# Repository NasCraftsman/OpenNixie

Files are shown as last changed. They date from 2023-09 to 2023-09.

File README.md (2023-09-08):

# OpenNixie 

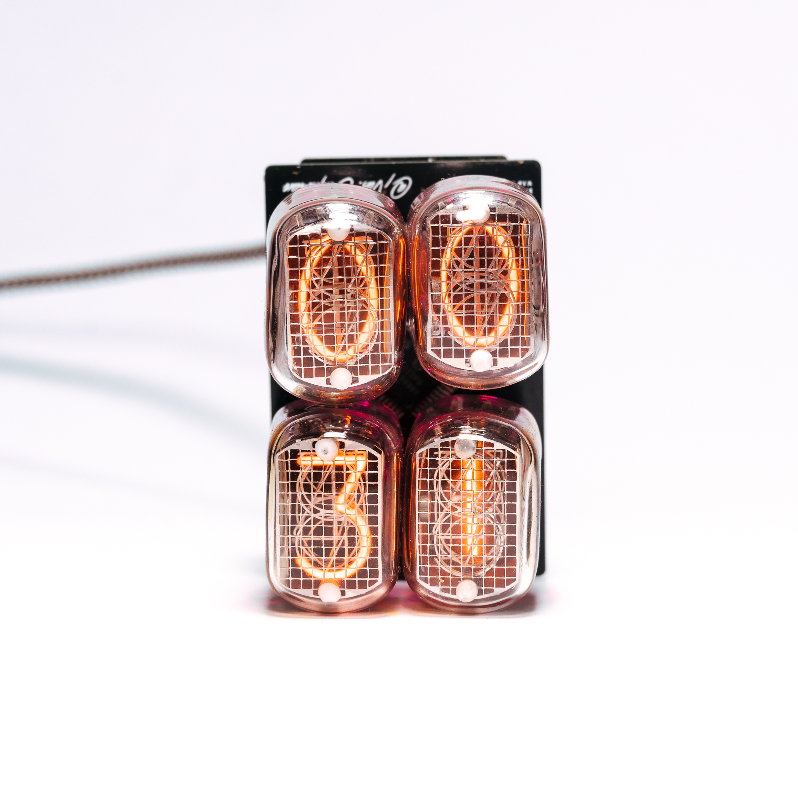
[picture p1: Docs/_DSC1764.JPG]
</a>
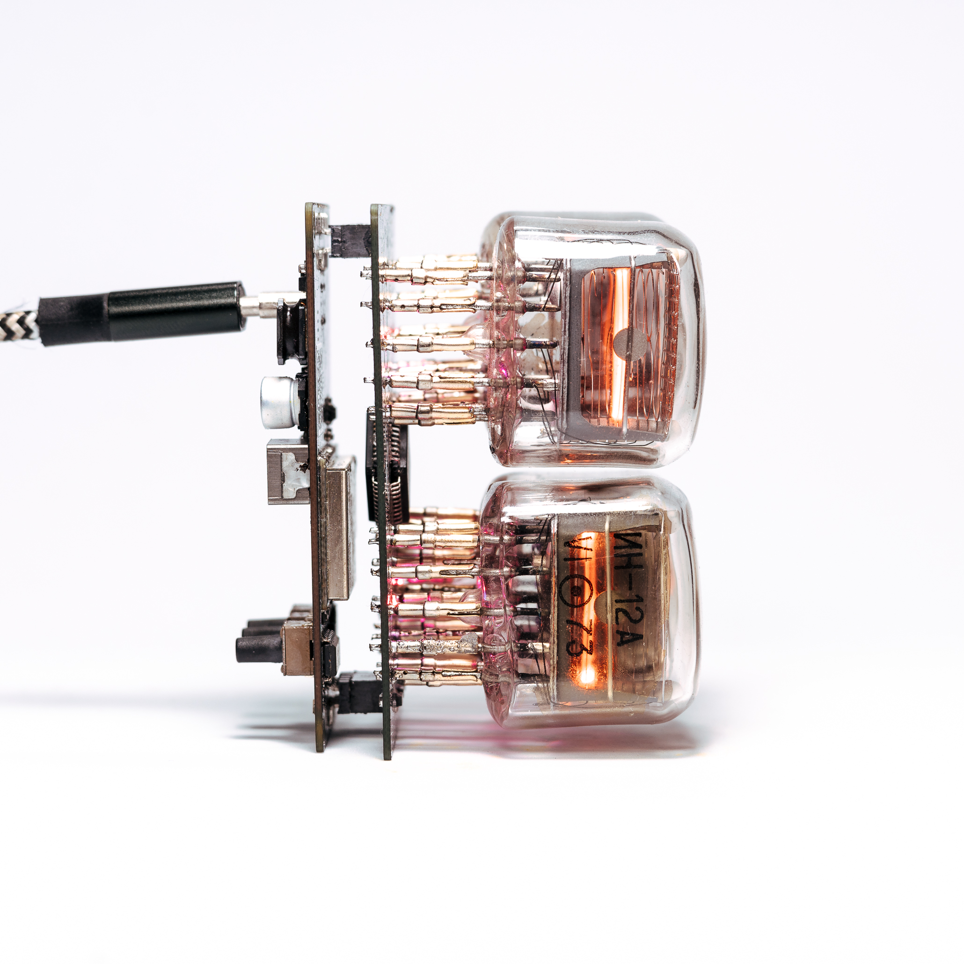
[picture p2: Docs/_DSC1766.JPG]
</a>
</a>

OpenNixie was born with the aim of creating an open project development platform around all types of Nixie Tubes. A platform that condenses the future with the past. The IoT technology with the famous plasma tubes in a miniature and modular design.

OpenNixie is a BLE and Wifi platform for different applications. It was originally designed as a RTC with an Internet connection, but later became a universal platform with many applications. This system is based on the ESP32-WROVER-IE Module, includes a 170V power stage and can be powered and programmed directly through the USB-C connector.

Some of the features that the OpenNixie platform includes are:

- Dimensions are only 30x60mm
- Wifi and BLE connected
- Modular design: it can be used for different Nixie tubes shapes and applications
- USB Type-C for power and programming
- 4 1N-12A + RGB lights as a default Nixie extension board 
- 1 general pourpose button for control the platform
- An internal accelerometer to interact with the display

<a href="https://www.pcbway.com/project/shareproject/Open_IoT_Nixie_Platform_9b133654.html" target="_blank">PCB from PCBWay</a>

## Multi Board Architecture
 
OpenNixie has been designed as a modular platform. This means that the control PCB can be connected to any PCB with Nixie tubes, so the applications are unlimited. At the moment the V2 version has been tested with a base for 4 1N-12A Nixies with RGB LEDs and SPI expansion.

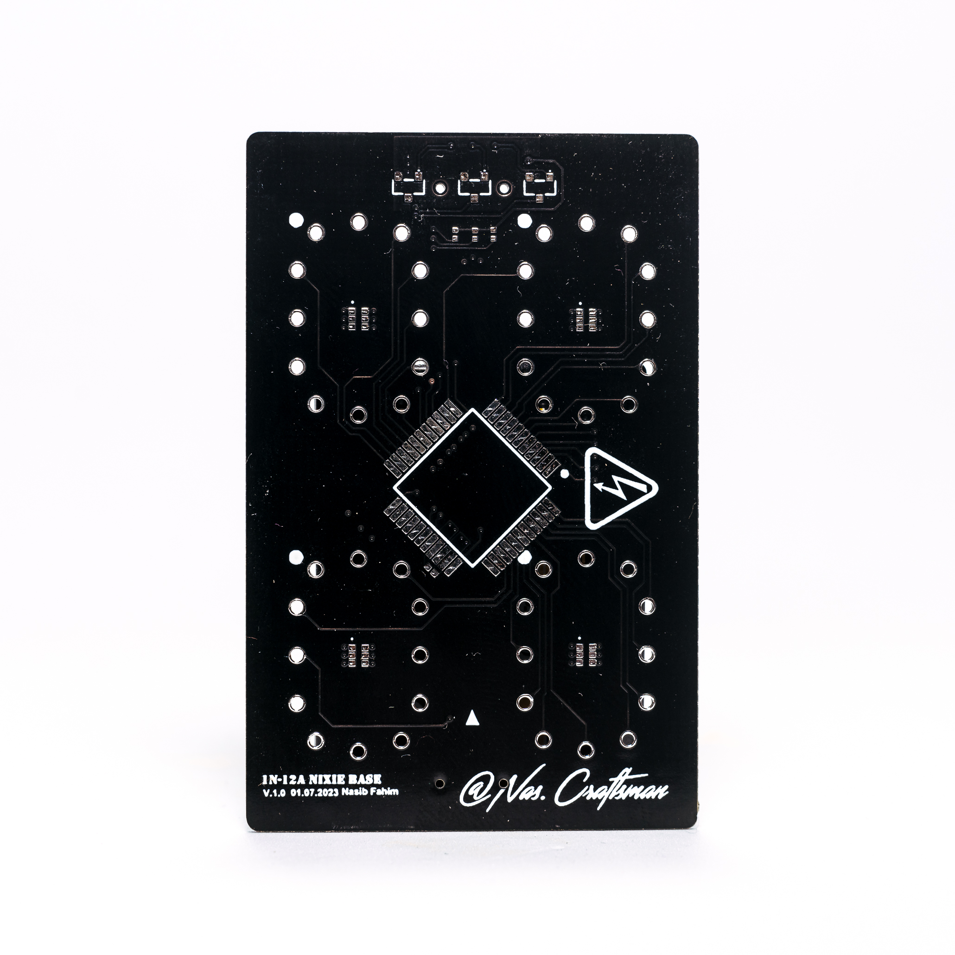
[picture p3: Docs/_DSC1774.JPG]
</a>
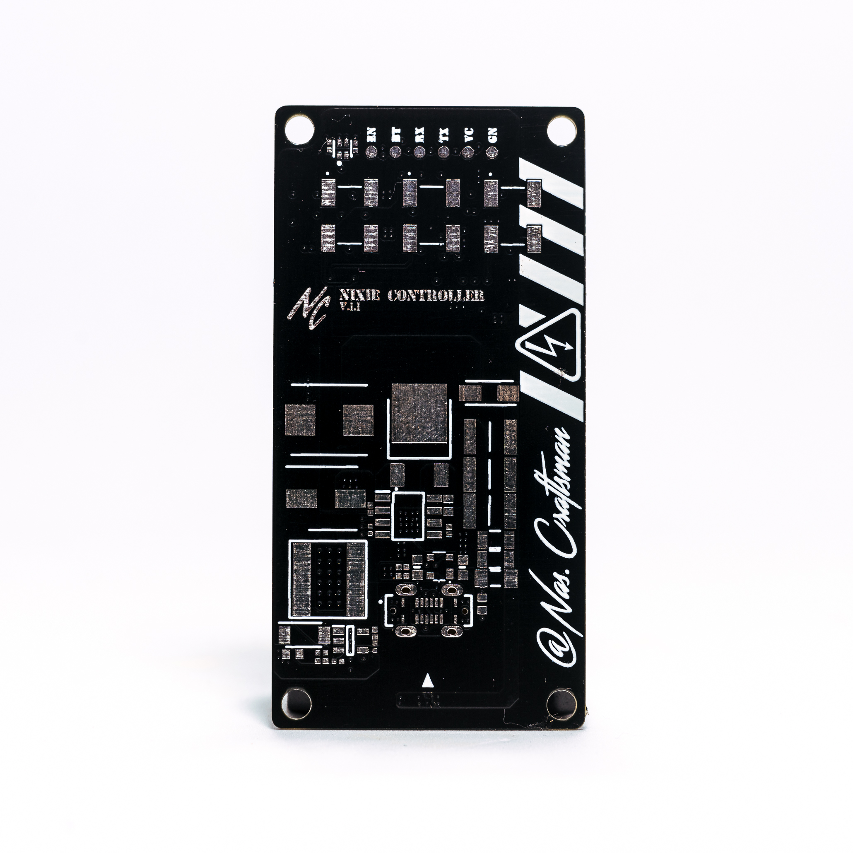
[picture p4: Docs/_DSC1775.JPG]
</a>

## Warning

OpenNixie uses the USB-C port to power the plasma tubes. For this, two power stages are created, one 12V LV and another 170V HV. The HV stage is limited to 1A, so it could be dangerous depending on the power supply used.

## GPIOs

Function | GPIO V2 | Mode
-------- | -------- | --------
SCK | GPIO2 | Output
MOSI | GPIO4 | Output
Button | GPIO15 | Input
I2C_SDA | GPI18 | Output/Input
I2C_SCL | GPI19 | Output
LED G | GPIO21 | Output
LED R | GPIO22 | Output
LED B | GPIO23 | Output
Logic EN | GPIO25 | Output
ACC INT | GPIO26 | Input
EN 170V | GPIO32 | Output
EN 12V | GPIO33 | Output

* The RGB signals control the background color of the ambient LEDs under the Nixie tubes
* The ACC INT signal is triggered by an event in the accelerometer
* The I2C bus controls the accelerometer
* To activate the Nixie tubes, the ignition sequence should be: EN12-ON EN170-OFF LE-ON
* To deactivate Nixie tubes, the shutdown sequence should be: LE-OFF EN170-ON EN12-OFF

## Control board overview 

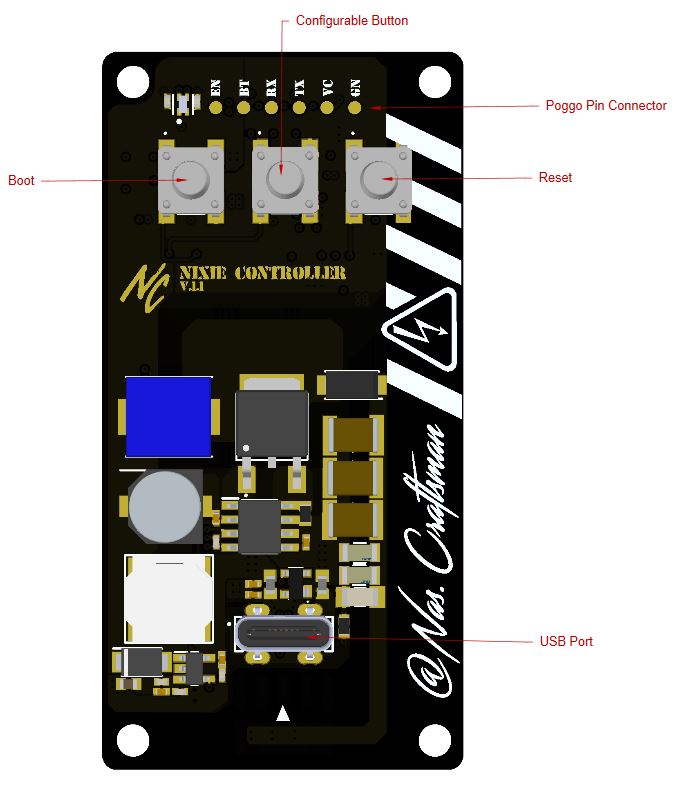
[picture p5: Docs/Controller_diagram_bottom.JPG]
</a>
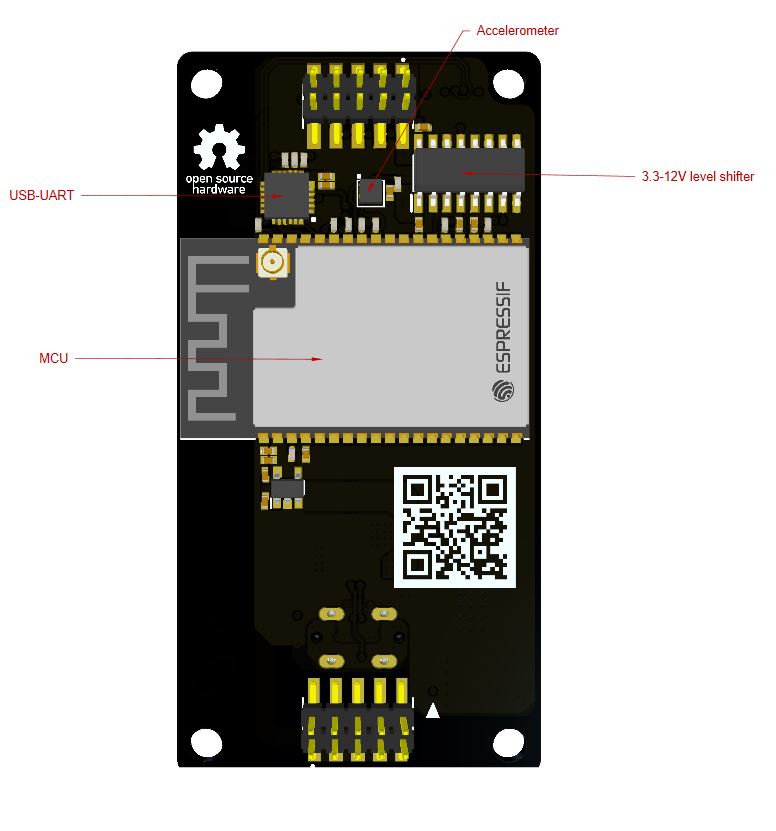
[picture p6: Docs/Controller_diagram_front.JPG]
</a>

## Flashing firmware 

- Press and hold BOOT button while press and release RESET button, then release BOOT button to enter in BOOT mode
- You can use the USB-C directly to programm the device

## Media

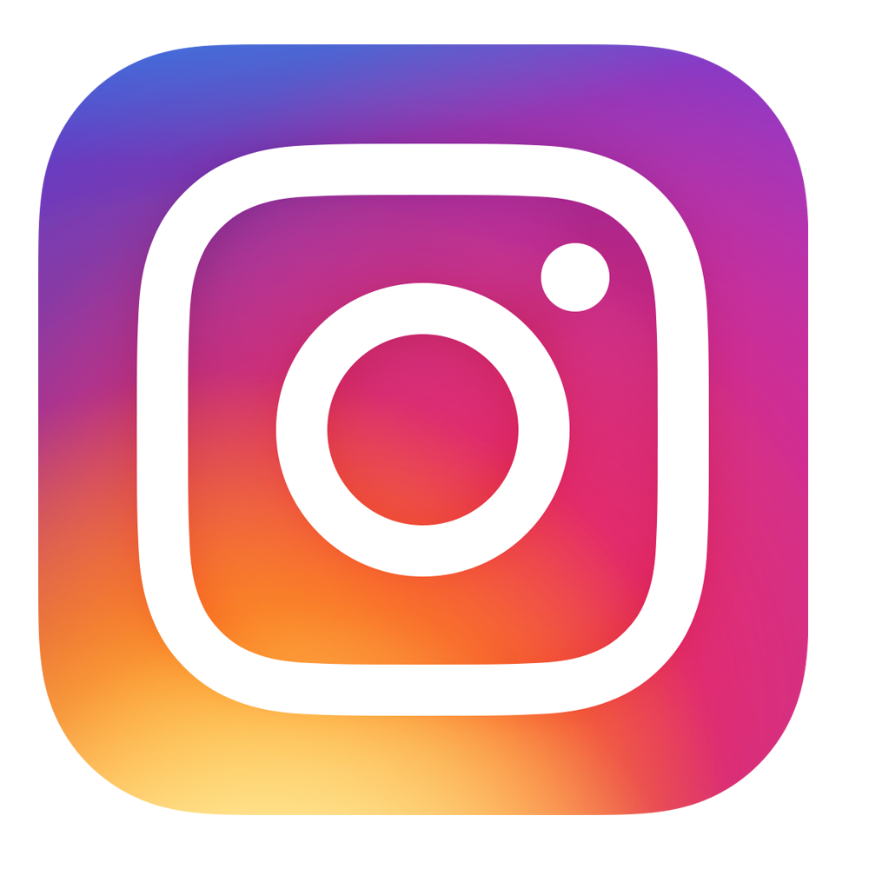
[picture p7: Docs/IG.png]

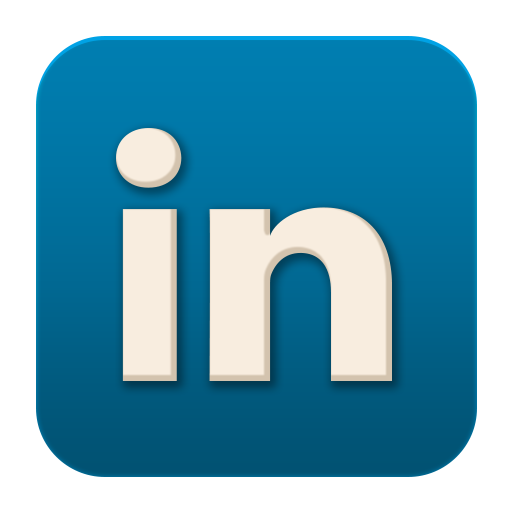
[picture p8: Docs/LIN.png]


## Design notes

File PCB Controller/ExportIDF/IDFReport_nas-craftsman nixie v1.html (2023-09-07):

Altium customize

# IDF File Translation Report

Date: | | 26/07/2023
Time: | | 13:23:11
Elapsed Time: | | 00:00:00
PCB Filename | : | F:\NASIB\INGENIERIA\PROYECTOS\Nixie project\V2\CONTROLLER\nas-craftsman nixie v1.PcbDoc
IDF Board Filename | : | F:\NASIB\INGENIERIA\PROYECTOS\Nixie project\V2\CONTROLLER\Project Outputs for nas-craftsman nixie v1\ExportIDF\nas-craftsman nixie v1.brd
IDF Library Filename | : | F:\NASIB\INGENIERIA\PROYECTOS\Nixie project\V2\CONTROLLER\Project Outputs for nas-craftsman nixie v1\ExportIDF\nas-craftsman nixie v1.pro

Errors

Back to top

Warnings

Back to top

Save Warnings

Back to top

Save Errors

Back to top

Export Warnings

Back to top

Export Errors

Back to top

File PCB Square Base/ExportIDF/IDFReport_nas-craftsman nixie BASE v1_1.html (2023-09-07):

Altium customize

# IDF File Translation Report

Date: | | 26/07/2023
Time: | | 13:10:11
Elapsed Time: | | 00:00:00
PCB Filename | : | F:\NASIB\INGENIERIA\PROYECTOS\Nixie project\V2\SQUARE BASE\nas-craftsman nixie BASE v1_1.PcbDoc
IDF Board Filename | : | F:\NASIB\INGENIERIA\PROYECTOS\Nixie project\V2\SQUARE BASE\Project Outputs for nas-craftsman nixie BASE v1\ExportIDF\nas-craftsman nixie BASE v1_1.brd
IDF Library Filename | : | F:\NASIB\INGENIERIA\PROYECTOS\Nixie project\V2\SQUARE BASE\Project Outputs for nas-craftsman nixie BASE v1\ExportIDF\nas-craftsman nixie BASE v1_1.pro

Errors

Back to top

Warnings

Back to top

Save Warnings

Back to top

Save Errors

Back to top

Export Warnings

Back to top

Export Errors

Back to top

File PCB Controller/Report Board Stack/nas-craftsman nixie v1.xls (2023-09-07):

Board Stack Report
Stack Up |  | Layer Stack
Layer | Board Layer Stack | Name | Material | Thickness | Constant
1 |  | Top Paste
2 |  | Top Overlay
3 |  | Top Solder | Solder Resist | 0,005mm | 4,2
4 |  | Top Layer | Copper | 0,035mm
5 |  | Dielectric 1 | PP-006 | 0,110mm | 4,1
6 |  | Mid1 | Copper | 0,035mm
7 |  | Core | FR-4 | 0,600mm | 4,29
8 |  | Mid2 | Copper | 0,035mm
9 |  | Dielectric 2 | PP-006 | 0,110mm | 4,1
10 |  | Bottom Layer | Copper | 0,035mm
11 |  | Bottom Solder | Solder Resist | 0,005mm | 4,2
12 |  | Bottom Overlay
13 |  | Bottom Paste
 | Height : 0,970mm

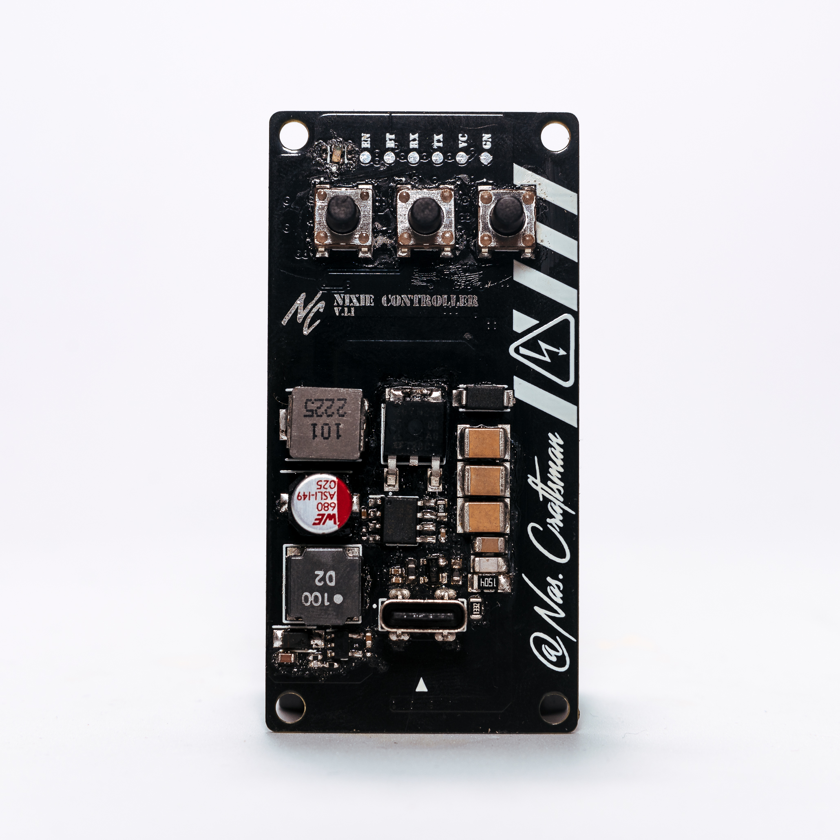
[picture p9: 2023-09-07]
Docs/_DSC1784.JPG

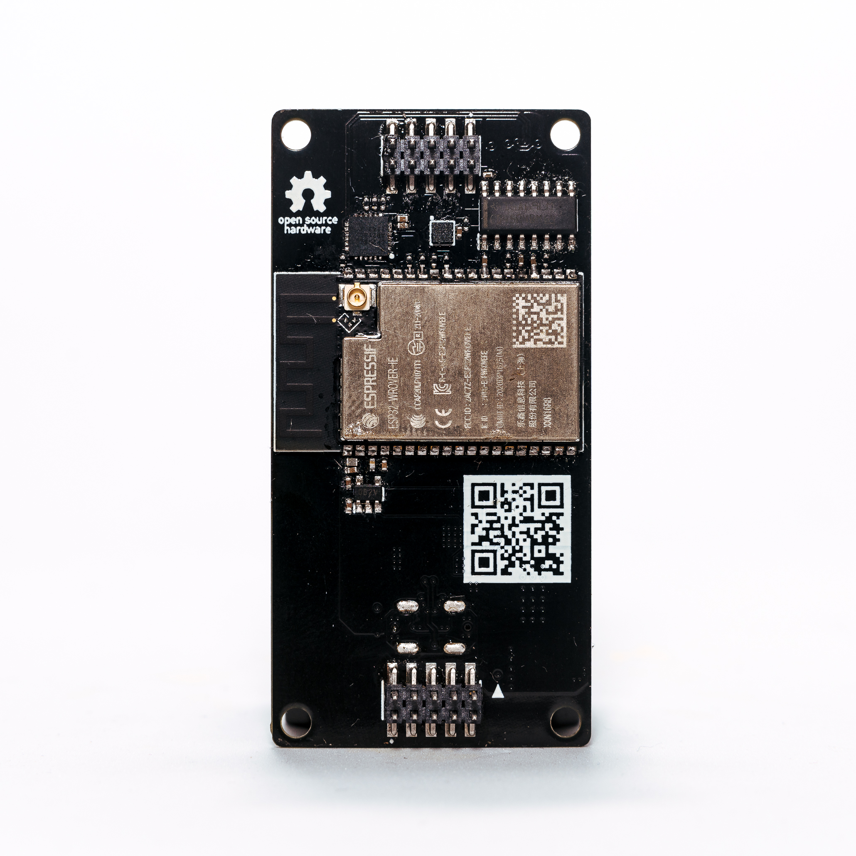
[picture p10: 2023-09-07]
Docs/_DSC1783.JPG

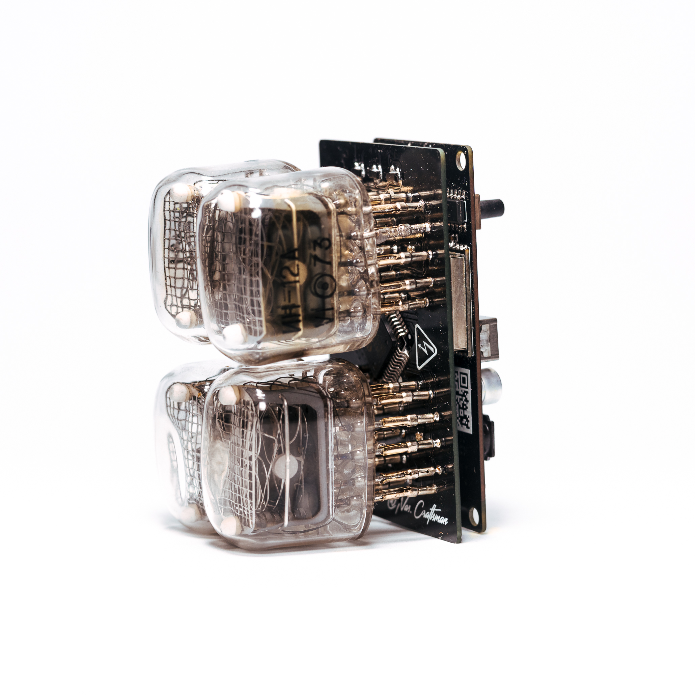
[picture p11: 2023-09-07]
Docs/_DSC1761.JPG

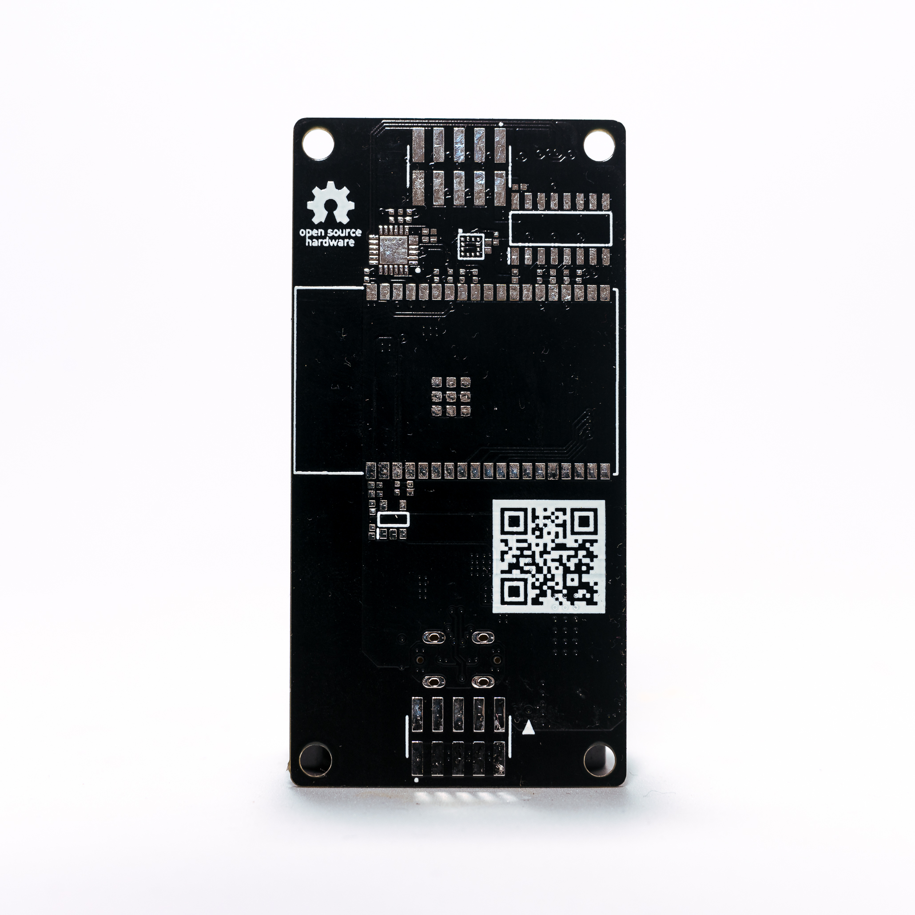
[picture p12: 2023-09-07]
Docs/_DSC1778.JPG

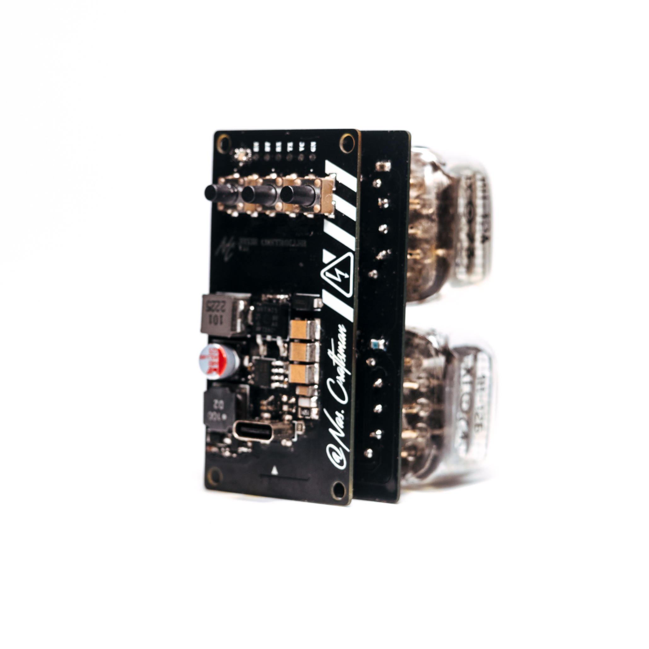
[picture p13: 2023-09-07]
Docs/_DSC1756.JPG

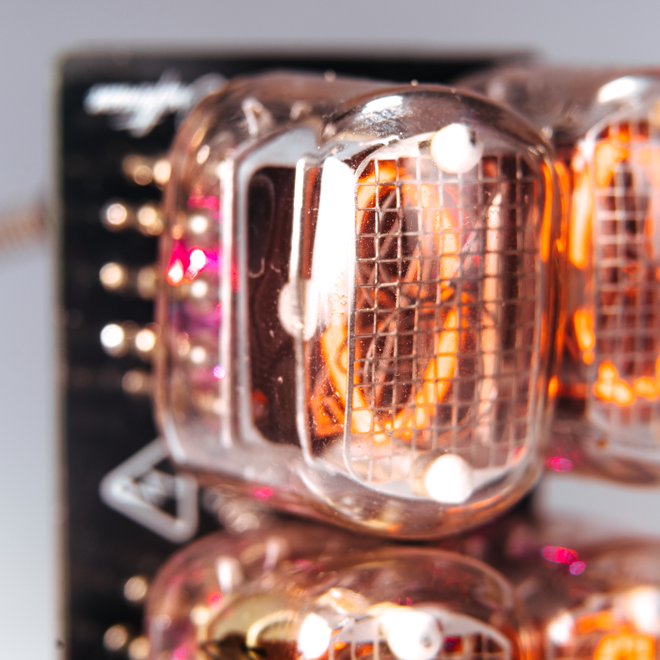
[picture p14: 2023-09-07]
Docs/_DSC1767.JPG

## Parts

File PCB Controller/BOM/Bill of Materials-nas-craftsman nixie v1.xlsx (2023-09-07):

Designator | Value | Description | Quantity | Part Number | Manufacturer | DNP
C100, C207, C208, C300, C302, C303, C304, C306, C307, C308, C309 | 100nF | CAP, MLCC, 0402/1005, 25V, X7R, | 11 | GRM155R71E104KE14D | Murata
C101 | 10nF | 0.01 uF 16 VDC 20% 0402 X7R | 1 | GRM155R71C103MA01D | Murata
C200, C201 | 1uF | 1.0uF 16V 10% 0402 X5R | 2 | GRM155R61C105KA12D | Murata
C203 | 10uF | 10 uF 25 VDC 10% 0603 X5R | 1 | GRM188R61E106KA73J | Murata Electronics
C204 | 270pF | 270 pF 25 VDC 5% 0402 C0G (NP0) | 1 | GRM1555C1E271JA01D | Murata
C205, C305 | 4.7uF | 4.7uF 10V 20% 0402 X5R | 2 | GRM155R61A475MEAAD | Murata
C206 | 68uF | SMD WCAP-ASLI 68uF 25V 20% SMD/SMT | 1 | 865080443009 | Wurth Elektronik
C209, C212, C213 | 1uF | 1812 MLCC X7R 1 uF, +/- 10% 200 V T&R GP | 3 | 1812B105K201CT | Walsin Technology Corporation
C210 | 100pF | 100 pF 500 VDC 5% 1206 C0G (NP0) | 1 | GRM31A5C2H101JW01D | Murata
C211 | 100nF | Cap Ceramic 100nF 250V X7R ±10% SMD 1206 +125°C Embossed T/R | 1 | CL31B104KEHSFNE | Samsung
C301 | 22uF | 22 uF 10 VDC 20% 0402 X5R | 1 | GRM158R61A226ME15D | Murata
D4 |  | LED GREEN/RED DIFFUSED 0603 SMD | 1 | HSMF-C165
D100 |  | Diode | 1 | PRTR5V0U2X | Nexperia
D200 |  | Super low VF Schottkey Barrier Diode for General rectification 2A 320mV | 1 | RBS2LAM40CTR | ROHM Semiconductor
D201 |  | Schottky 200V 3A | 1 | SS320-HF | Comchip Technology
FB100, FB101 |  | Ferrite Bead, 2A @ 100MHz, 120ohms 25% | 2 | ILHB0603ER121V | Vishay
J100 |  |  | 1 | USB4120-03-C | GCT
J101, J102 |  | Connector | 2 | TMM-105-01-T-D-SM-TR | SAMTEC
L200 |  | 8040 10uH 44.2mOhms +/-20% 3.1A | 1 | NR8040T100M | TAIYO YUDEN
L201 |  | 100uH+/-20%, 2.2A 357mOhms | 1 | SRP7050WA-101M | Bourns
Q200 |  | MOSFET N-Channel 250V AEC-Q101 Qualified | 1 | SQD07N25-350H_GE3 | Vishay
R200 | 118k | SMD 118 kOhms 62.5mW 0402 1% | 1 | RC0402FR-07118KL | Yageo
R201 | 13.3k | SMD 13.3 kOhms 62.5mW 0402 1% | 1 | RC0402FR-0713K3L | Yageo
R202, R203 | 100k | SMD 100kOhms 1/16W 0402 5% | 2 | RC0402JR-7D100KL | Yageo
R204 | 50m | SMD 0.05 ohm 0603 1% 0.20W | 1 | KDV06FR050ET | Ohmite
R205 | 1.5M | SMD 1.5 MOhms 250 mW 1206 1% | 1 | RC1206FR-071M5L | Yageo
R206 | 13.3k | SMD 13.3 kOhms 125 mW 0805 1% | 1 | RC0805FR-0713K3L | Yageo
R300, R307, R308 | 10k | SMD 10 kOhms 62.5mW 0402 1% | 3 | RC0402FR-0710KL | Yageo
R301 | 1M | SMD 1 MOhms 62.5mW 0402 5% | 1 | RC0402JR-071ML | Yageo
R302, R303 | 270 | RES SMD 270OHM 5% 1/16W 0402 | 2 | RC0402JR-07270RL | Yageo
R304 | 1k | SMD 1 kOhms 62.5mW 0402 5% | 1 | RC0402JR-071KL | Yageo
R305 | 22.1k | SMD 22.1kOhms 1/16W 0402 1% | 1 | RC0402FR-0722K1P | Yageo
R306 | 47.5k | SMD 47.5 kOhms 62.5mW 0402 1% | 1 | RC0402FR-0747K5L | Yageo
R309, R310 | 4k7 | SMD 4.7 kOhms 62.5mW 0402 5% | 2 | RC0402JR-074K7L | Yageo
R311, R312, R313 | 100 | SMD 100 Ohms 62.5mW 0402 1% | 3 | RC0402FR-07100RL | Yageo
S300, S302, S303 |  | Switch | 3 | TL3301BF160QJ | E-Switch
U200 |  | 700mA High Speed LDO Regulator | 1 | XC6210B332MR-G | Torex
U201 |  | 1.5A 1.6MHZ BOOST CONVERTER | 1 | LM2731XMF/NOPB | Texas Instruments
U202 |  | Integrated Circuit | 1 | MAX1771CSA+ | Analog Devices
U300 |  | RX TXRX MOD WIFI EXT IPEX SMD | 1 | ESP32-WROVER-IE(M213EH2864UH3Q0) | Espressif
U301 |  | Integrated Circuit | 1 | MC3479 | MEMSIC
U302 |  | USB to UART Bridge QFN24 | 1 | CP2102N-A02-GQFN24R | Silicon Labs
U303 |  | CMOS Quad Lo-to-Hi Vltg Level Shifter | 1 | CD4504BM96 | Texas Instruments

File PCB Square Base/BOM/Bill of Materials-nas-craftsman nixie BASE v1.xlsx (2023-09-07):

Designator | Value | Description | Quantity | Part Number | Manufacturer | DNP
C100, C101 | 100nF | CAP, MLCC, 0402/1005, 25V, X7R, | 2 | GRM155R71E104KE14D | Murata
J100, J101 |  | Connector | 2 | TLE-105-01-G-DV-A | SAMTEC
LED100, LED101, LED102, LED103 |  | LED | 4 | IN-S66TFT5R5G5B | Inolux
N100, N101, N102, N103 |  | Undefined or Miscellaneous | 4 | 1N- 12A | Reflector/Sovtec | DNP
Q100, Q101, Q102 |  | MOSFET (N-Channel) | 3 | T2N7002AK,LM | Toshiba
R100, R101, R102, R103 | 15.8k | SMD 1/4W 15.8K OHM 1% | 4 | RK73H2ATTD1582F | KOA Speer
R104 | 200 | SMD 200 Ohms 62.5 mW 0402 1% | 1 | RE0402FRE07200RL | Yageo
R105, R106 | 150 | SMD 150 Ohms 62.5mW 0402 1% | 2 | RC0402FR-07150RL | Yageo
U100, U101 |  | HV OD Outs Serial to Parallel Converter | 2 | HV5222PG-G | Microchip

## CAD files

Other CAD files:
PCB Square Base/ExportSTEP/nas-craftsman nixie BASE v1_1.x_t

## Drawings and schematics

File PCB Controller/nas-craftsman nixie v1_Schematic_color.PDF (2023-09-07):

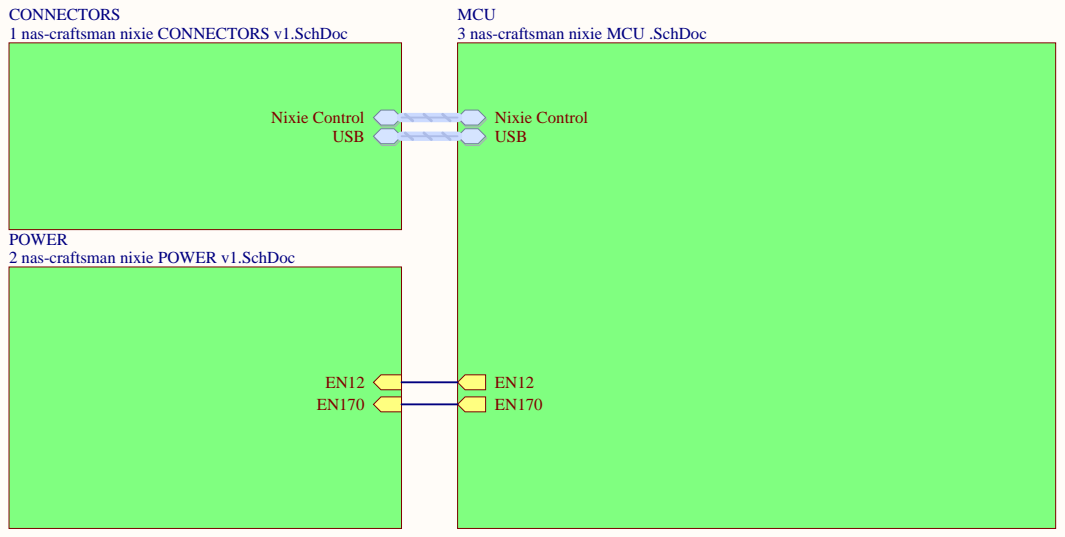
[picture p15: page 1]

CONNECTORS
1 nas-craftsman nixie CONNECTORS v1.SchDoc

MCU
3 nas-craftsman nixie MCU .SchDoc

POWER
2 nas-craftsman nixie POWER v1.SchDoc

Title MAIN

Number 0 | Project nas-craftsman nixie v1.PrjPcb | Revision v1

Created by: Nasib Fahim Fernández | | Date 26/07/2023

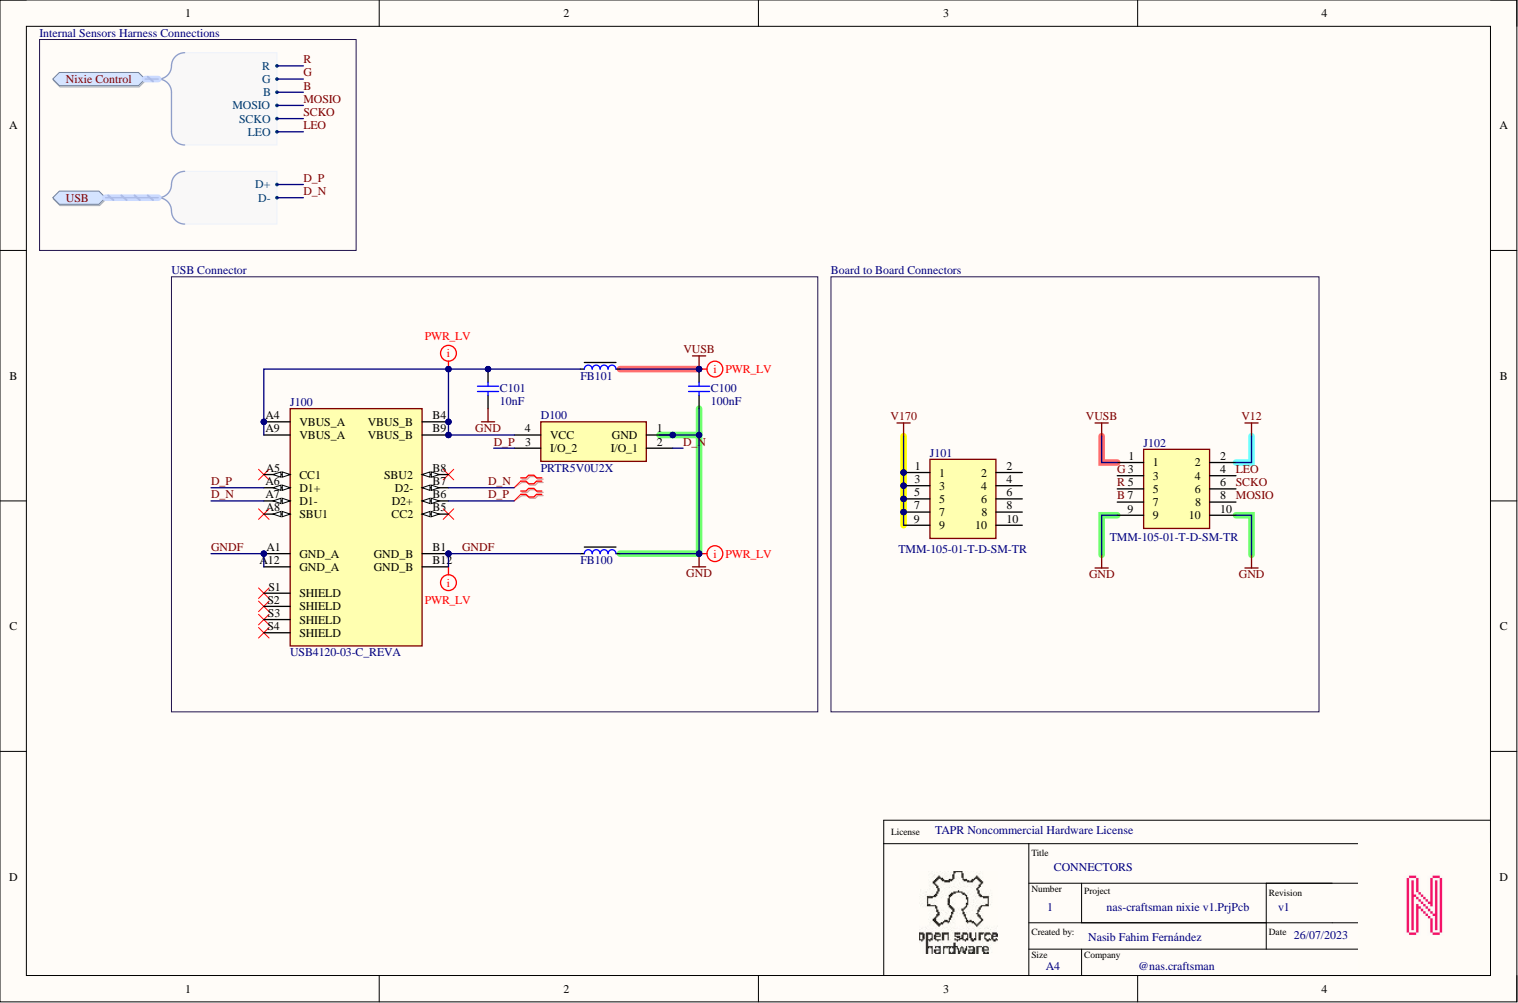
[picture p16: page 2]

Internal Sensors Harness Connections

Title CONNECTORS

Number 1 | Project nas-craftsman nixie v1.PrjPcb | Revision v1

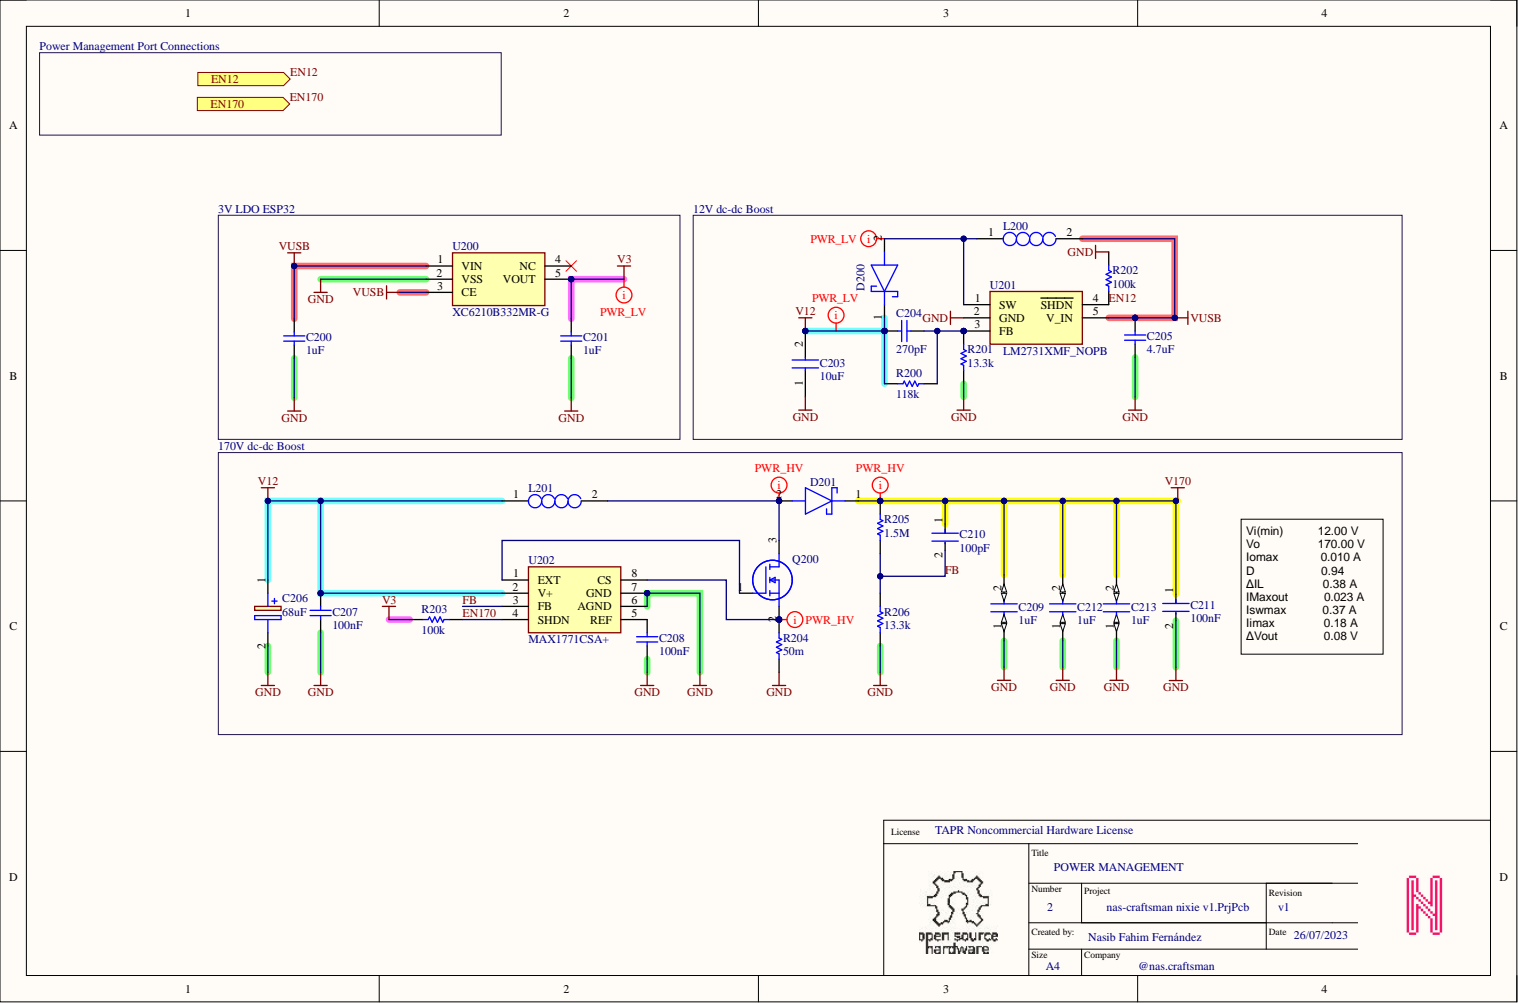
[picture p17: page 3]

Power Management Port Connections

Title POWER MANAGEMENT

Number 2 | Project nas-craftsman nixie v1.PrjPcb | Revision v1

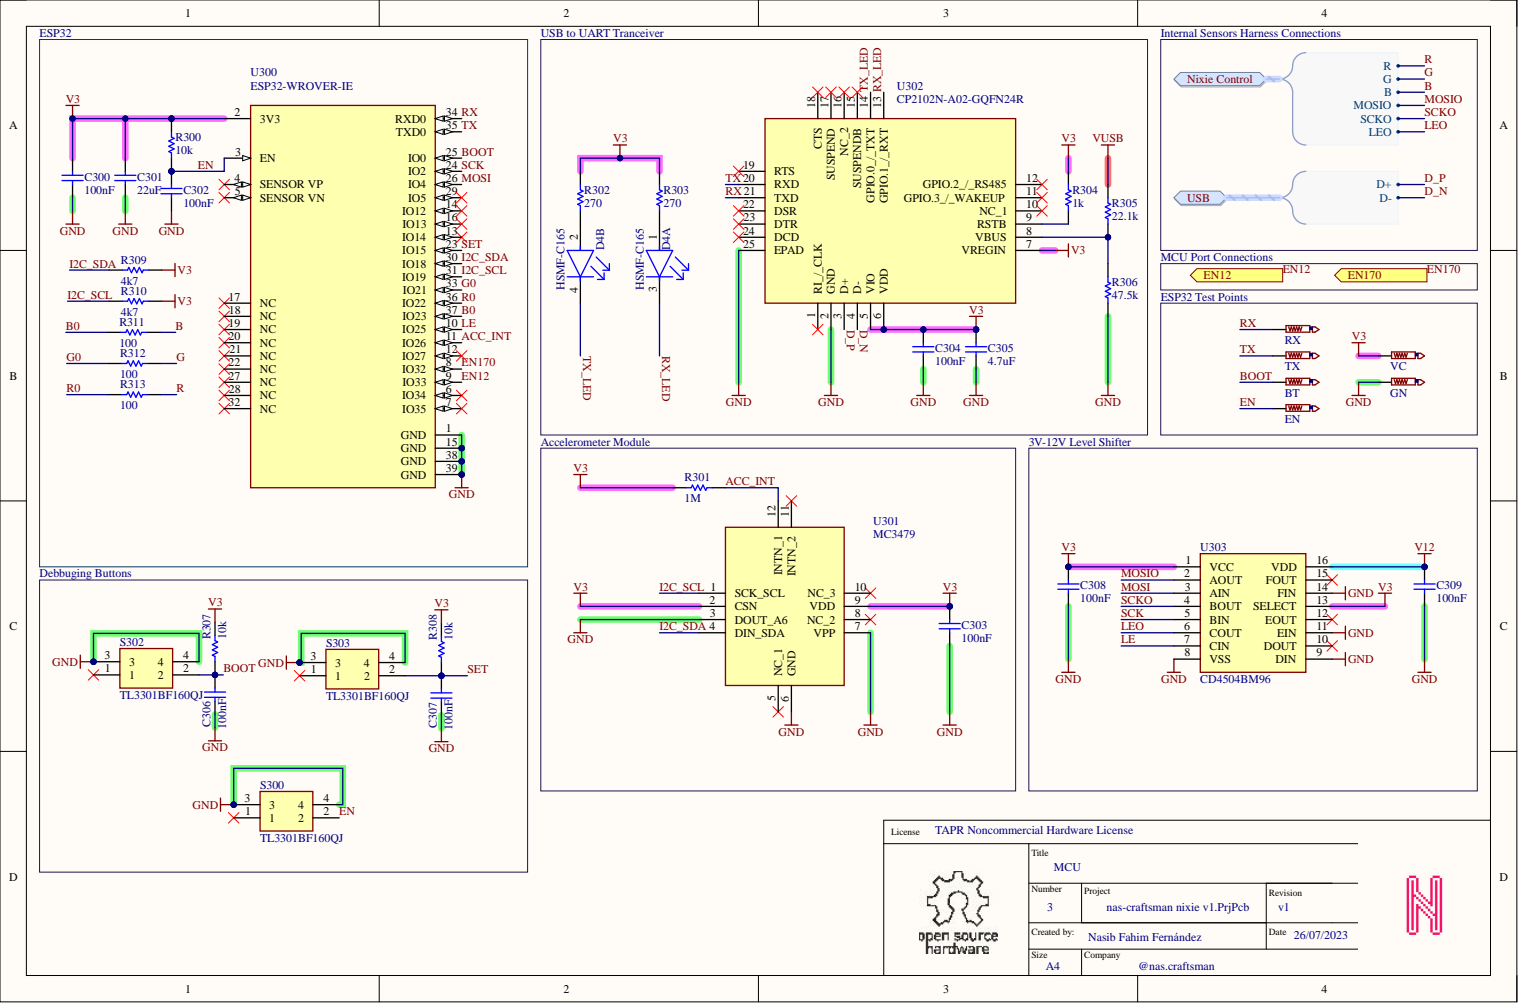
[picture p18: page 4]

USB to UART Tranceiver

Internal Sensors Harness Connections

EN | | SENSOR VN 5 SENSOR VP 4

Title MCU

Number 3 | Project nas-craftsman nixie v1.PrjPcb | Revision v1

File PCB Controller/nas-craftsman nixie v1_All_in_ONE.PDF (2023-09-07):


CONNECTORS
1 nas-craftsman nixie CONNECTORS v1.SchDoc

MCU
3 nas-craftsman nixie MCU .SchDoc

POWER
2 nas-craftsman nixie POWER v1.SchDoc

Title MAIN

Number 0 | Project nas-craftsman nixie v1.PrjPcb | Revision v1

Created by: Nasib Fahim Fernández | | Date 26/07/2023


Internal Sensors Harness Connections

Title CONNECTORS

Number 1 | Project nas-craftsman nixie v1.PrjPcb | Revision v1

Created by: Nasib Fahim Fernández | | Date 26/07/2023


Power Management Port Connections

Title POWER MANAGEMENT

Number 2 | Project nas-craftsman nixie v1.PrjPcb | Revision v1

Created by: Nasib Fahim Fernández | | Date 26/07/2023


USB to UART Tranceiver

Internal Sensors Harness Connections

EN | | SENSOR VN 5 SENSOR VP 4

Title MCU

Number 3 | Project nas-craftsman nixie v1.PrjPcb | Revision v1

Created by: Nasib Fahim Fernández | | Date 26/07/2023

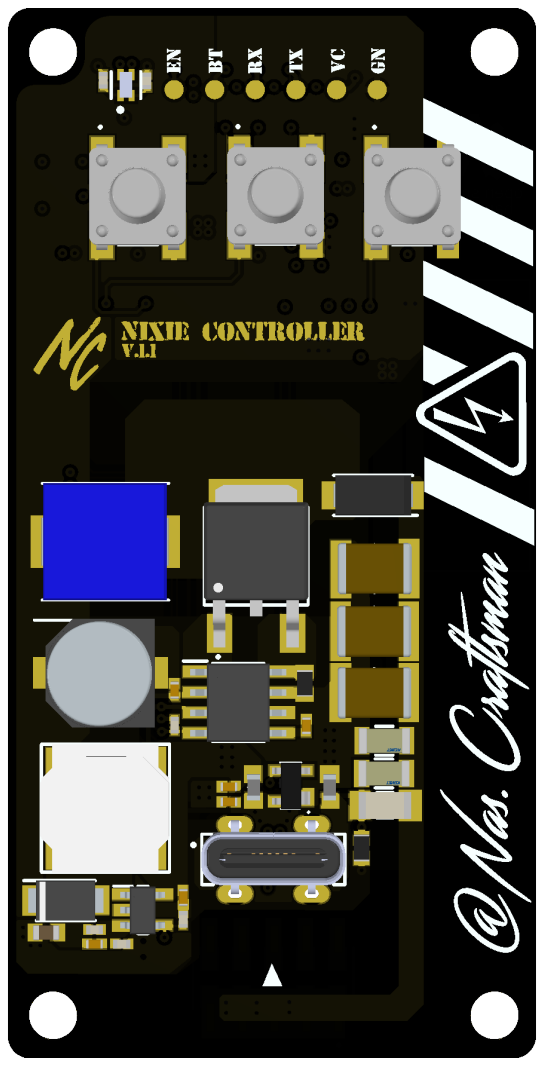
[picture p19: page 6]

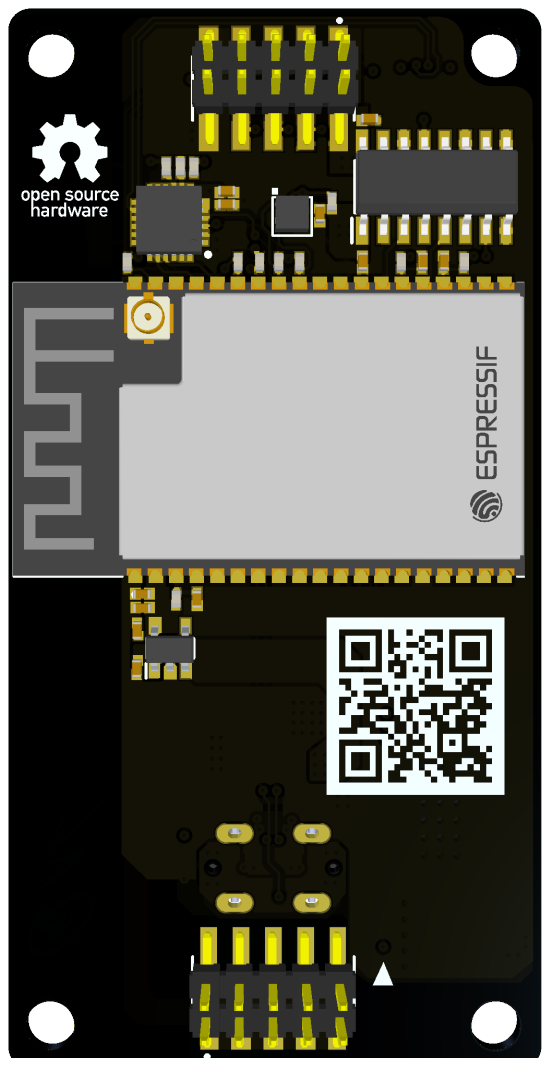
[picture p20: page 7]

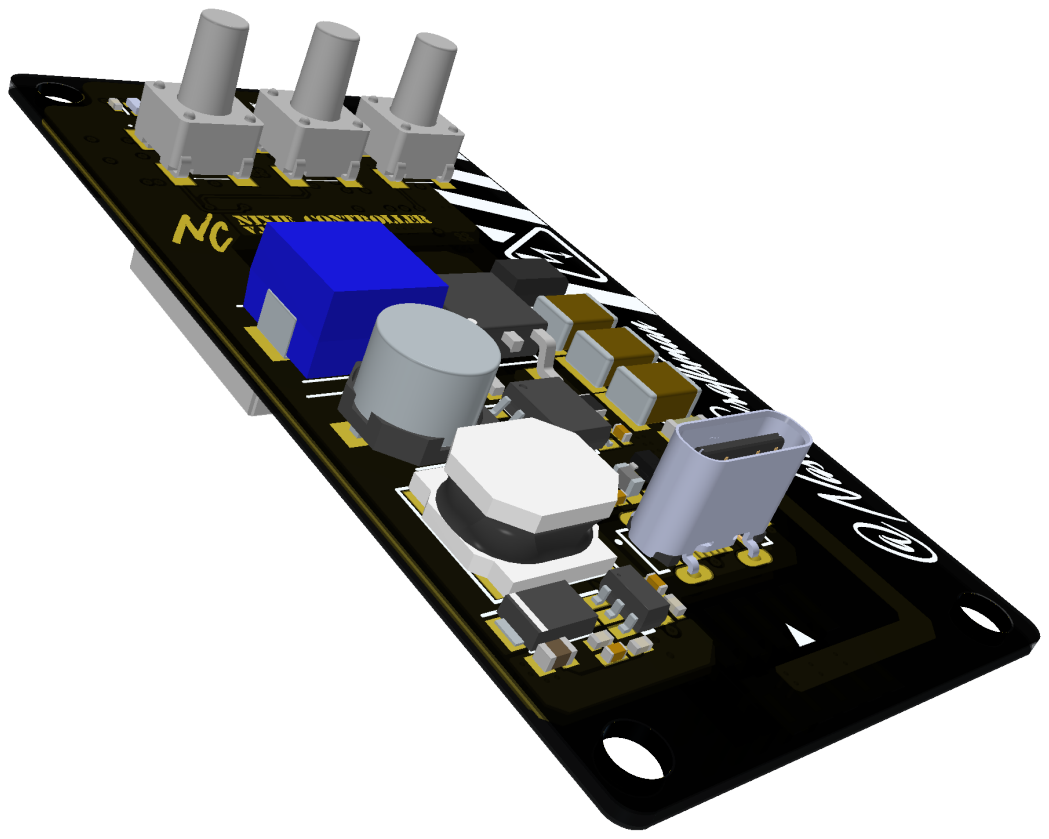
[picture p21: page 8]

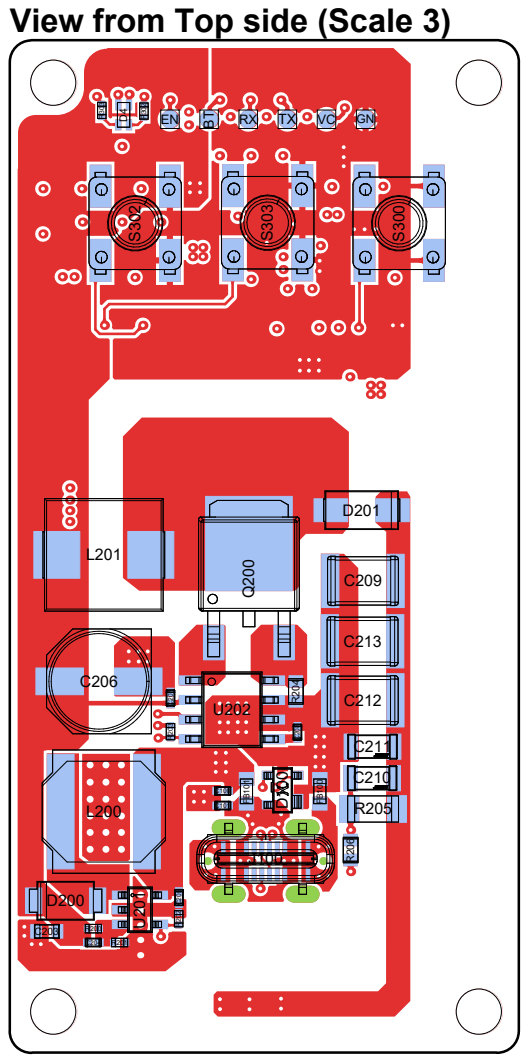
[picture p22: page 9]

View from Top side (Scale 3)

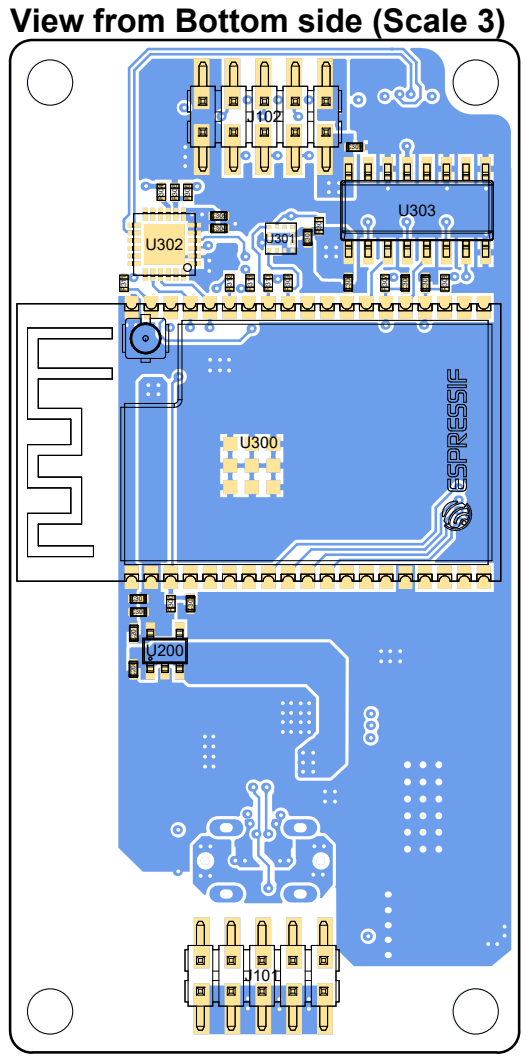
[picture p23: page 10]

View from Bottom side (Scale 3)

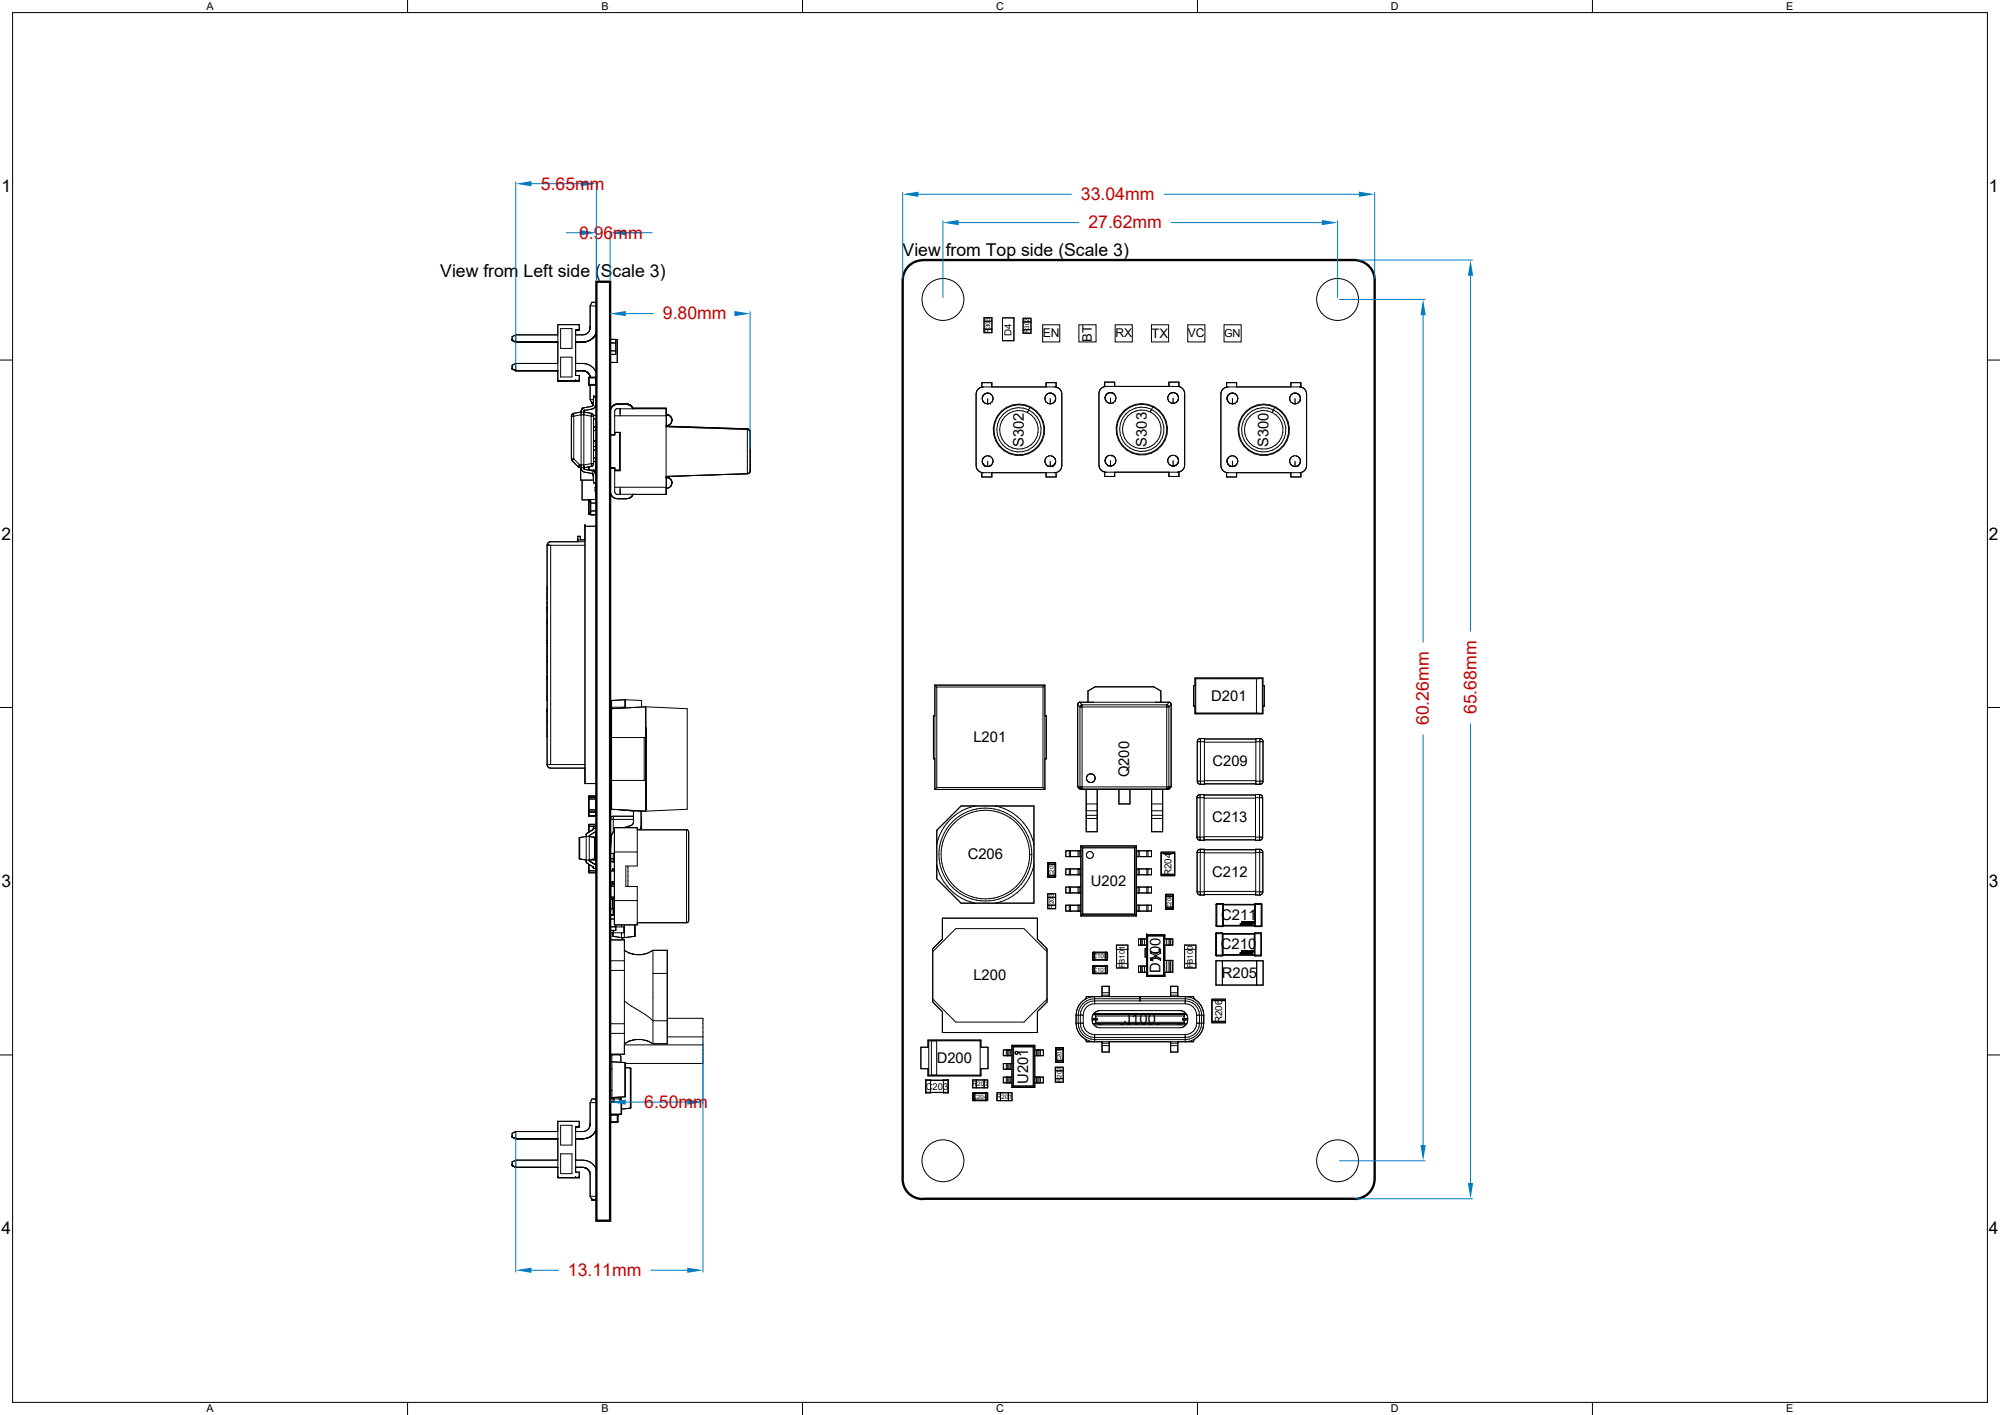
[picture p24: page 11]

View from Top side (Scale 3)

View from Left side (Scale 3)

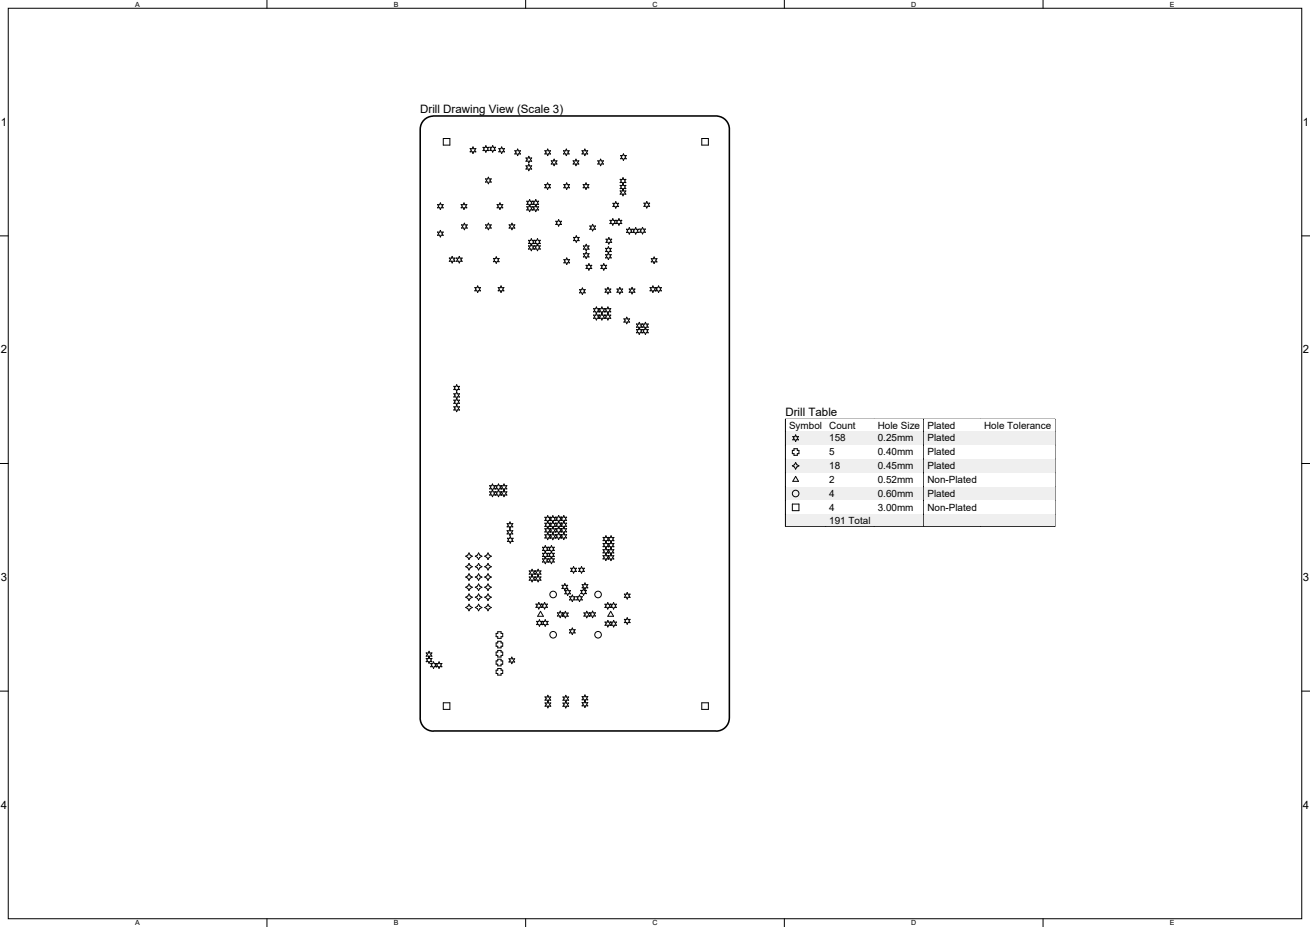
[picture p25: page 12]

Drill Drawing View (Scale 3)

Symbol | Count | Hole Size | Plated | Hole Tolerance

158 | 0.25mm | Plated
5 | 0.40mm | Plated
18 | 0.45mm | Plated
2 | 0.52mm | Non-Plated
4 | 0.60mm | Plated
4 | 3.00mm | Non-Plated
191 Total

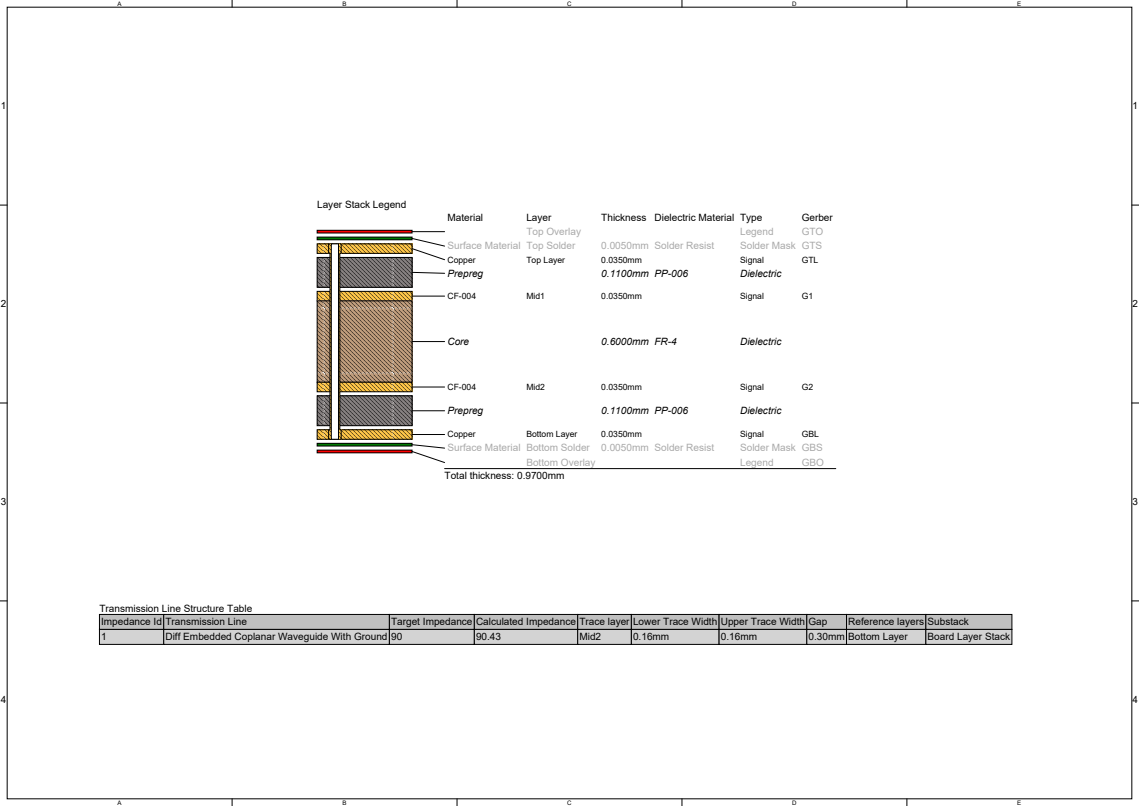
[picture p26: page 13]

Transmission Line Structure Table

Impedance Id | Transmission Line | Target Impedance | Calculated Impedance | Trace layer | Lower Trace Width | Upper Trace Width | Gap | Reference layers | Substack
1 | Diff Embedded Coplanar Waveguide With Ground | 90 | 90.43 | Mid2 | 0.16mm | 0.16mm | 0.30mm | Bottom Layer | Board Layer Stack





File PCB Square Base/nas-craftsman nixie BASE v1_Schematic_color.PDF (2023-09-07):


Title MAIN

Number 0 | Project nas-craftsman nixie BASE v1.PrjPcbv1 | Revision

Created by: Nasib Fahim Fernández | | Date 26/07/2023

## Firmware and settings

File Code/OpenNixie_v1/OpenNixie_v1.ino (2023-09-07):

//////////////////////////////////////////////////////////////////////////////////////////////////////////////////////
//
//  OPEN NIXIE FANTASY PROJECT
//
//  Modes: (press fast two times the center button to change the mode)
//  * Mode0-dice
//  * Mode1-cronometer 
//  * Mode2-universal clock 
//  * Mode3-work break counter
//
//  The circuit:
//  * This code is made to be used with the NixeFantasy Controller V2 and the NixieFantasy Square Base V2
//
//  The License: 
//  * Created in 2023 by nas.craftsman https://github.com/NasCraftsman
//  * This example code is in the public domain.
//
//////////////////////////////////////////////////////////////////////////////////////////////////////////////////////
//                       NixieFantasy Square Base V1
//
//    Nixie 1:N100
//    o o
//    o x
//    clk 1-10
//  
//    Nixie 2:N101
//    o o
//    x o
//    clk 11-20
//  
//    Nixie 3:N101
//    x o
//    o o
//    clk 21-30
//    Nixie 4:N100
//    o x
//    o o
//    clk 31-40
//
//////////////////////////////////////////////////////////////////////////////////////////////////////////////////////


#include <WiFi.h>
#include <AsyncTCP.h>
#include <ESPAsyncWebServer.h>
#include <HTTPClient.h>
#include "time.h"

const char* ssid     = "prue";
const char* password = "ojetecalor";
const char* ntpServer = "pool.ntp.org";
const long  gmtOffset_sec = 0;
const int   daylightOffset_sec = 3600;

#define SET       15      // General purpose button
#define SCK       2       // SPI sck pin
#define MOSI      4       // SPI MOSI pin
#define MISO      27       // SPI MISO pin
#define SS        34       // SPI MISO pin
#define SDA       18      // I2C SDA pin
#define SCL       19      // I2C SCL pin
#define R         22      // R LEDs pin
#define G         21      // G LEDs pin
#define B         23      // B LEDs pin
#define LE        25      // Nixies serial-parallel enable pin
#define ACC_INT   26      // Accelerometer interrupt pin 
#define EN_170    32      // 170V Enable pin 
#define EN_12     33      // 12V Enable pin 

#define LEDC_TIMER_13_BIT  13   // Use 13 bit precission for LEDC timer
#define LEDC_BASE_FREQ     5000 // Use 5000 Hz as a LEDC base frequency 
#define LEDC_CHANNEL_0     0    // Use first channel of 16 channels (started from zero)
#define LEDC_CHANNEL_1     1
#define LEDC_CHANNEL_2     2

//-----------------------AP PARAMETERS------------------------------------//
/* Put your SSID & Password */
const char* ssid_ap = "NIXIES";  // Enter SSID here
const char* password_ap = "12345678";  //Enter Password here

/* Put IP Address details */
IPAddress local_ip(192,168,1,1);
IPAddress gateway(192,168,1,1);
IPAddress subnet(255,255,255,0);

//--------------------WEBSERVER PARAMETERS-------------------------------//
AsyncWebServer  server(80);

const char* PARAM_INPUT_1 = "input1";
const char* PARAM_INPUT_2 = "input2";
String inputMessage1;
String inputMessage2;
String inputParam1;
String inputParam2;

//--------------------HTTP CLIENT PARAMETERS-----------------------------//
const char* serverName = "http://192.168.0.14:8000/";

//--------------------GLOBAL VARIABLES-----------------------------------//
String states[4]={"DICES MODE","CRONOMETER MODE","UNIVERSAL CLOCK MODE","TAKE A REST MODE"};
byte hour=0;
byte minute=0;
byte connection_counter=0;
byte one_time_2=0;
byte number_of_dices=2;
byte faces_of_dices=6;
int button_state=0;
int lastTriggerMillis=0;
int lastTriggerMillis_function=0;
int s=0;
int s10=0;
int m=0;
int m10=0;
int rest_period=120;
int clock_period=1;
int dice_values[4]={0,0,0,0};
bool dices_rolled=0;
bool parameters_received=0;
bool acc_flag=0;
bool button_flag=0; 
bool one_time=0;
bool button_released=0;
bool is_connected=false;
byte pinArray[40]={0,0,0,0,0,0,0,0,0,0,0,0,0,0,0,0,0,0,0,0,0,0,0,0,0,0,0,0,0,0,0,0,0,0,0,0,0,0,0,0};

//---------------------------------------------------------------------------------------------------ANALOG CONTROL FOR LEDS------------------------------------------------------------------------------------------
// Arduino like analogWrite
void ledcAnalogWrite(uint8_t channel, uint32_t value, uint32_t valueMax = 255) {
  uint32_t duty = (8191 / valueMax) * min(value, valueMax);  // calculate duty, 8191 from 2 ^ 13 - 1
  ledcWrite(channel, duty);  // write duty to LEDC
}
//---------------------------------------------------------------------------------------------------CONTROL LEDS------------------------------------------------------------------------------------------------------

void LEDS(int Re, int Gr, int Bl){
  ledcAnalogWrite(LEDC_CHANNEL_0, Re);//100
  ledcAnalogWrite(LEDC_CHANNEL_1, Gr);//100
  ledcAnalogWrite(LEDC_CHANNEL_2, Bl);//20
}
//---------------------------------------------------------------------------------------------------TURN ON NIXIES---------------------------------------------------------------------------------------------------

void turn_on(){
  digitalWrite(EN_12, HIGH);
  delay(10); 
  digitalWrite(EN_170, LOW);
  delay(10);
  digitalWrite(LE, HIGH);
}
//---------------------------------------------------------------------------------------------------TURN OFF NIXIES--------------------------------------------------------------------------------------------------
void turn_off(){
  digitalWrite(LE, LOW);
  digitalWrite(EN_170, HIGH);
  delay(10);
  digitalWrite(EN_12, LOW);
  delay(10); 
}
//---------------------------------------------------------------------------------------------------RESET NIXIES------------------------------------------------------------------------------------------------------
void reset(){
  int a_r=0;
  digitalWrite(EN_12, HIGH);
  delay(10);
  digitalWrite(MOSI, LOW);
  delay(1);
  while(a_r<40){ 
      digitalWrite(SCK,HIGH);
      delay(1);
      digitalWrite(SCK,LOW);
      delay(1);
      a_r++;
  }
  a_r=0;
  digitalWrite(EN_12, LOW);
  delay(10);
}
//---------------------------------------------------------------------------------------------------CREATE A FLUSH ANIMATION----------------------------------------------------------------------------------------------
void flus(int vel){
  turn_off();
  turn_on(); 
  digitalWrite(MOSI, HIGH);
  delay(1);
  for(int i=0;i<=40;i++){ 
      digitalWrite(SCK,HIGH);
      delay(vel);
      digitalWrite(SCK,LOW);
      delay(vel);
      digitalWrite(MOSI, LOW);
      delay(1); 
  }
  turn_off(); 
}
//---------------------------------------------------------------------------------------------------CONTROL ONE NIXIE------------------------------------------------------------------------------------------------------
void set_number( int n_nixie, int number ){
  if(number>9){
    number=9;
  }
  if(n_nixie>4){
    n_nixie=4;
  }
  if(n_nixie==1){
    number=number+0;
  }
  else if(n_nixie==2){
    number=number+10;
  }
  else if(n_nixie==3){
    number=number+20;
  }
  else{
    number=number+30;
  }
  turn_off();
  reset();
  digitalWrite(EN_12, HIGH);
  delay(10); 
  digitalWrite(MOSI, HIGH);
  delay(1);
  for(int i=0;i<=number;i++){ 
      digitalWrite(SCK,HIGH);
      delay(1);
      digitalWrite(SCK,LOW);
      delay(1);
      digitalWrite(MOSI, LOW);
      delay(1);
  }
  turn_on(); 
}
//---------------------------------------------------------------------------------------------------CONTROL 4 NIXIES------------------------------------------------------------------------------------------------------
void set_four_numbers(int n1, int n2, int n3, int n4){
  long long nixie1=1<<10-n1-1;
  long long nixie2=1<<10-n2-1;
  long long nixie3=1<<10-n3-1;
  long long nixie4=1<<10-n4-1;
  long long final_nixie=(nixie1<<30)+(nixie2<<20)+(nixie3<<10)+(nixie4<<0);
  byte pin=0;
  for(int i=0;i<=40;i++){
    pin=(final_nixie>>(i))&1;
    pinArray[40-i]=pin;
  } 
  turn_off();
  reset();
  digitalWrite(EN_12, HIGH);
  delay(10);
  digitalWrite(SCK,LOW);
  delay(1);
  digitalWrite(MOSI, LOW);
  delay(1);
  for(int i=0;i<40;i++){ 
        if(pinArray[40-i]){
          digitalWrite(MOSI, HIGH);
          delay(1);
        }
        digitalWrite(SCK,HIGH);
        delay(1);
        digitalWrite(SCK,LOW);
        delay(1);
        digitalWrite(MOSI, LOW);
        delay(1); 
    }
  turn_on(); 
}
//---------------------------------------------------------------------------------------------------PRINT TIME FROM SERVER------------------------------------------------------------------------------------------------------
byte  printLocalTime(){
      double m=0;
      double h=0; 
      byte h1=0;
      byte h2=0;
      byte m1=0;
      byte m2=0;
      
      struct tm timeinfo;
      
      while(!getLocalTime(&timeinfo)){
          delay(500);
          Serial.println("Failed to obtain time");
          connection_counter++;
            if(connection_counter>=5){
              Serial.println("Unable to obtain time");
              Serial.println("________________________________");
              return 0;
            }
      }
        
        hour = timeinfo.tm_hour;
        minute = timeinfo.tm_min;
        Serial.print("Hour:");
        Serial.println(hour);
        Serial.print("Minute:");
        Serial.println(minute);
        if(hour>9){
          h2=hour/10;
          h=hour;
          h=((h/10)-h2)*100;
          h1=h/10; 
        }
        else{
          h1=hour;
          h2=0;
        }
        if(minute>9){
          m2=minute/10;
          m=minute;
          m=((m/10)-m2)*100;
          m1=m/10;
        }
        else{
          m1=minute;
          m2=0;
        }
        set_four_numbers(m1,m2,h2,h1);
        Serial.println("________________________________");
        return 1;

}
//---------------------------------------------------------------------------------------------------DICE FUNCTION------------------------------------------------------------------------------------------------------
void dice(byte n_dices, byte f_dices){
  byte place=0;
  byte place_played[4]={5,5,5,5};
  byte played_flag=1;
  
  if(!digitalRead(SET)){
    button_released=0;
    if(!one_time){ 
      Serial.println("Sacking....");
      lastTriggerMillis_function=millis();
      one_time=1;
    }
    LEDS(100,100,20);
    flus(10);
  }
  else if(button_released){   
        if(one_time){
            Serial.println("Rolling dice...");
            for(int i=0;i<n_dices;i++){
                    while(played_flag==1){
                          place=random(0,4);
                          played_flag=0;
                          for(int n=0;n<n_dices;n++){
                                if(place_played[n]==place){
                                  played_flag=1;
                                }
                          }
                    }
                    played_flag=1;
                    place_played[i]=place;
                    dice_values[place]=random(1,f_dices+1);
                    Serial.print("Position of dice ");
                    Serial.print(i);
                    Serial.print(": ");
                    Serial.println(place_played[i]);
                    Serial.print("Value of dice ");
                    Serial.print(i);
                    Serial.print(": ");
                    Serial.println(dice_values[place]);
             }
            Serial.println("________________________________");
            set_four_numbers(dice_values[2],dice_values[0],dice_values[3],dice_values[1]);
            lastTriggerMillis_function=millis();
            dices_rolled=1;
        }
    one_time=0;
  }
  if(dices_rolled){
    for(int i=0;i<4;i++){
          dice_values[i]=0;
          place_played[i]=5;
      }
    if((millis()-lastTriggerMillis_function)>3000){
      flus(5);
      turn_off();
      dices_rolled=0;
    }
  }
}
//---------------------------------------------------------------------------------------------------CRONOMETER FUNCTION------------------------------------------------------------------------------------------------------
void cronometer(){
    if(!digitalRead(SET)){
        button_released=0;
        if(!one_time){
         
          Serial.println("Are you ready!?");
          lastTriggerMillis_function=millis();
          one_time=1;
        }
        if((millis()-lastTriggerMillis_function)>300){
          LEDS(100,100,20);
          flus(10);
        }
  }
  else if(button_released){
    if((millis()-lastTriggerMillis_function)>1000){
        if(one_time){
          lastTriggerMillis_function=millis();
          Serial.println("Go!");
          s=0;
          s10=0;
          m=0;
          m10=0;
          while(digitalRead(SET)&&!button_flag){
               LEDS(100,100,20);
               if((millis()-lastTriggerMillis_function)>=1000){
                  s++;
                  if(s>9){
                      s=0;
                      s10++;
                  }
                  if(s10>=6){
                      s10=0;
                      m++;
                  }
                  if(m>9){
                      m=0;
                      m10++;
                  }
                  if(m10>=6){
                      m10=0;
                  }
                  lastTriggerMillis_function=millis(); 
                  set_four_numbers(s,s10,m10,m);
                 }
          }
          LEDS(0,0,0);
        }
    }
    one_time=0;
  }
}
//---------------------------------------------------------------------------------------------------CLOCK FUNCTION-----------------------------------------------------------------------------------------------
void universalclock(int period, bool modes){
   if(one_time_2==0){
            Serial.println("Setting time");
            configTime(gmtOffset_sec, daylightOffset_sec, ntpServer); 
            Serial.println("Printing time");
            printLocalTime();
            lastTriggerMillis_function=millis();
            one_time_2++;
            Serial.println("________________________________");
   }
   if(millis()-lastTriggerMillis_function>60000*period){
              Serial.println("Setting time");
              configTime(gmtOffset_sec, daylightOffset_sec, ntpServer); 
              Serial.println("Printing time");
              printLocalTime();
              lastTriggerMillis_function=millis();
              one_time_2=1;
              Serial.println("________________________________");
   }
   if(!modes){
               if(millis()-lastTriggerMillis_function>2000){
                      if(one_time_2==1){
                        flus(5);
                        turn_off();
                        one_time_2++;
                      }
                }
   }
  else{
                if(millis()-lastTriggerMillis_function>2000){
                      if(one_time_2==1){
                          for(int i=0;i<5;i++){
                                flus(5);
                          }
                          turn_off();
                          one_time_2++;
                       }  
                }          
 }
}
//---------------------------------------------------------------------------------------------------ACCELEROMETER INTERRUPT--------------------------------------------------------------------------------------
void acc(){
 acc_flag=1;
}
//---------------------------------------------------------------------------------------------------BUTTON INTERRUT-----------------------------------------------------------------------------------------------
void but(){
    if((millis() - lastTriggerMillis)<200){
      button_state++;
      if(button_state>3){
        button_state=0;
      } 
      button_flag++;
  }
  button_released=1;
  lastTriggerMillis=millis();
}
// HTML web page to handle 3 input fields (input1, input2, input3)
//---------------------------------------------------------------------------------------------------WEB SERVER------------------------------------------------------------------------------------------------------
const char index_html[] PROGMEM = R"rawliteral(
  <!DOCTYPE HTML>
  <html>
    <head>
      <title>ESP Input Form</title>
      <meta name="viewport" content="width=device-width, initial-scale=1">
      <style> body { background-color: #808080; font-family: Arial, Helvetica, Sans-Serif; Color: #000000; text-align:center; }</style>
    </head>
    
    <body>
    <h3>Enter your WiFi credentials</h3>
    <form action="/get">
        USR: <input type="text" name="input1"><br>
        PASS: <input type="password" name="input2"><br><br>
        <input type="submit" value="Submit">
    </form><br>
    </body>
  </html>
)rawliteral";


//---------------------------------------------------------------------------------------------------404 ERROR------------------------------------------------------------------------------------------------------

void notFound(AsyncWebServerRequest *request) {
  request->send(404, "text/plain", "Not found");
}

//---------------------------------------------------------------------------------------------------WEB SERVER CONFIG------------------------------------------------------------------------------------------------------
void WEB_SERVER_config(){

  // Send web page with input fields to client
  server.on("/", HTTP_GET, [](AsyncWebServerRequest *request){
    request->send_P(200, "text/html", index_html);
  });

  // Send a GET request to <ESP_IP>/get?input1=<inputMessage>
  server.on("/get", HTTP_GET, [] (AsyncWebServerRequest *request) {

    // GET input1 value on <ESP_IP>/get?input1=<inputMessage>
    if (request->hasParam(PARAM_INPUT_1)) {
      inputMessage1 = request->getParam(PARAM_INPUT_1)->value();
      inputParam1 = PARAM_INPUT_1;
       parameters_received++;
    }
    // GET input2 value on <ESP_IP>/get?input2=<inputMessage>
    if (request->hasParam(PARAM_INPUT_2)) {
      inputMessage2 = request->getParam(PARAM_INPUT_2)->value();
      inputParam2 = PARAM_INPUT_2;
       parameters_received++;
    }
   
    else {
      inputMessage1 = "No message sent";
      inputParam1 = "none";
      inputMessage2 = "No message sent";
      inputParam2 = "none";
       parameters_received=0;
    }
    Serial.println("Parameters Received From Client:");
    Serial.print(inputParam1);
    Serial.print(":");
    Serial.println(inputMessage1);
    Serial.print(inputParam2);
    Serial.print(":");
    Serial.println(inputMessage2);
    Serial.println("________________________________");
    
    request->send(200, "text/html", "PARAMETERS SENT CORRECTLY"
                                     "<br><br><a href=\"/\">Return to Home Page</a>");
  });

  server.onNotFound(notFound);
  server.begin();
  Serial.println("HTTP server started");
  
}

//---------------------------------------------------------------------------------------------------MANAGE INFO FROM SERVER------------------------------------------------------------------------------------------------
void manage_info(){
 if( parameters_received!=0){
    WiFi.softAPdisconnect();
    Serial.println("Disconnecting AP");
    WiFi.mode(WIFI_STA);
    Serial.print("Connecting to:");
    Serial.println(inputMessage1.c_str());
    Serial.print("With PASS:");
    Serial.println(inputMessage2.c_str());
    WiFi.begin(inputMessage1.c_str(), inputMessage2.c_str());
    if (WiFi.waitForConnectResult() != WL_CONNECTED) {
      Serial.println("WiFi Failed!");
      Serial.println("Configuring local AP Server...");
      WiFi.softAP(ssid_ap, password_ap);
      WiFi.softAPConfig(local_ip, gateway, subnet);
      delay(100);
      Serial.println("Local AP Server Configured!");
      parameters_received=0; 
      is_connected=false;
      return;
    }
    //ENCENDER TODOS LOS LEDS EN VERDE 
    Serial.println("Connected to Wifi!");
    Serial.print("IP Address: ");
    Serial.println(WiFi.localIP());
    parameters_received=0;
    is_connected=true;
    Serial.println("________________________________");
  }
}
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
void loop() {
  
      manage_info();
      
      if(button_flag){
        set_four_numbers(button_state,button_state,button_state,button_state);
        LEDS(100,100,20);
        delay(200);
        flus(3);
        turn_off();
        LEDS(0,0,0);
        button_flag=0;
        one_time=0;
        one_time_2=0;
        Serial.println("________________________________");
        Serial.println(states[button_state]);
        Serial.print("Connection:");
        Serial.println(is_connected);
        Serial.println("________________________________");
       
      }
      
      if(button_state==0){
        dice(number_of_dices,faces_of_dices);
      }
      else if(button_state==1){
        cronometer();
      }
      else if(button_state==2 && is_connected){
        universalclock(clock_period,0);
      }
      else if(button_state==3 && is_connected){
        universalclock(rest_period,1); 
      }

}
